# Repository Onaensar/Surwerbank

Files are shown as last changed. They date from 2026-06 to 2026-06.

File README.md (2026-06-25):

# Surwerbank
# Hybrid Powerbank: Solar + MagSafe + 18W Fast Charge 

Welcome to the **Hybrid Survivor Powerbank** repository! This project is a fully open-source, high-efficiency power management board designed for ultimate portability and outdoor resilience. 

Unlike standard powerbanks, this board integrates **18W Bidirectional Fast Charging**, **MPPT Solar Energy Harvesting**, and **MagSafe Compatible Wireless Charging** into a single, compact PCB.

**Designed by:** Abdullah Ensar 
**Institution:** İzmir Bakırçay University, Electrical and Electronics Engineering

---

## ✨ Key Features & Core ICs

### 1. ⚡ 18W Fast Charging & Power Management (IP5328P)
At the heart of the board is the **IP5328P** SoC, handling high-efficiency bi-directional charging. 
* Supports multiple fast-charge protocols (QC3.0, PD, AFC, FCP).
* Stable 5A output capability for demanding devices.
* Deeply filtered power delivery with strategic capacitor placement (low ripple).

### 2. ☀️ MPPT Solar Harvesting (CN3791)
Built for off-grid scenarios, the board includes a dedicated **CN3791** Maximum Power Point Tracking (MPPT) circuit.
* Connect a compatible solar panel to the terminal block.
* Extracts maximum available power from the sun to trickle-charge the lithium cells, significantly extending standby and active use time in outdoor environments.

### 3. 🧲 Wireless & MagSafe Charging (IP6808)
No cables? No problem. The **IP6808** wireless charging transmitter ensures your devices stay powered up seamlessly.
* Optimized resonance capacitor array for stable Tx transmission.
* Designed to be highly compatible with MagSafe form factors.

### 4. 🛡️ Rugged & Enclosure-Ready Mechanical Design
This PCB isn't just an electrical prototype; it is designed for real-world mechanical integration.
* **Mounting Holes:** M3 mounting holes placed at the corners for secure installation inside 3D printed or waterproof enclosures.
* **Optimized Clearances:** Type-C receptacle (J2) is perfectly aligned with the board edge (Edge.Cuts) to ensure flush mounting and cable compatibility.
* *Note: The mechanical STEP file is included for easy integration into Fusion 360 / SolidWorks to design custom rugged cases.*

---

## 🛠️ Fabrication & Assembly (Gerber Files)
The board has passed all DRC checks with 0 Errors and 0 Warnings in KiCad. 
* **Layer Count:** 2 Layers
* **Copper Weight:** 1 oz (recommended) or 2 oz for enhanced thermal dissipation under 5A loads.
* **Polygons:** Generous Top and Bottom GND pours with extensive via stitching for thermal relief and low impedance.

You can find the production-ready `.zip` file containing all Gerber and Drill files in the `Fabrication` folder.

## 📄 License
This project is released under the **Open Source Hardware (OSHW)** license. Feel free to use, modify, and build upon this design!

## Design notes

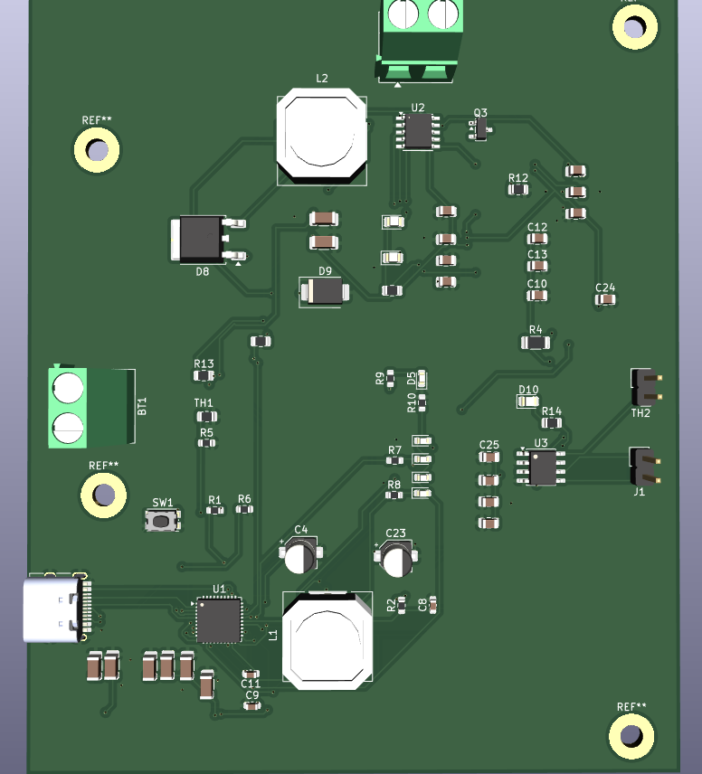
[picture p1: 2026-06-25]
Docs/3D_Render.png

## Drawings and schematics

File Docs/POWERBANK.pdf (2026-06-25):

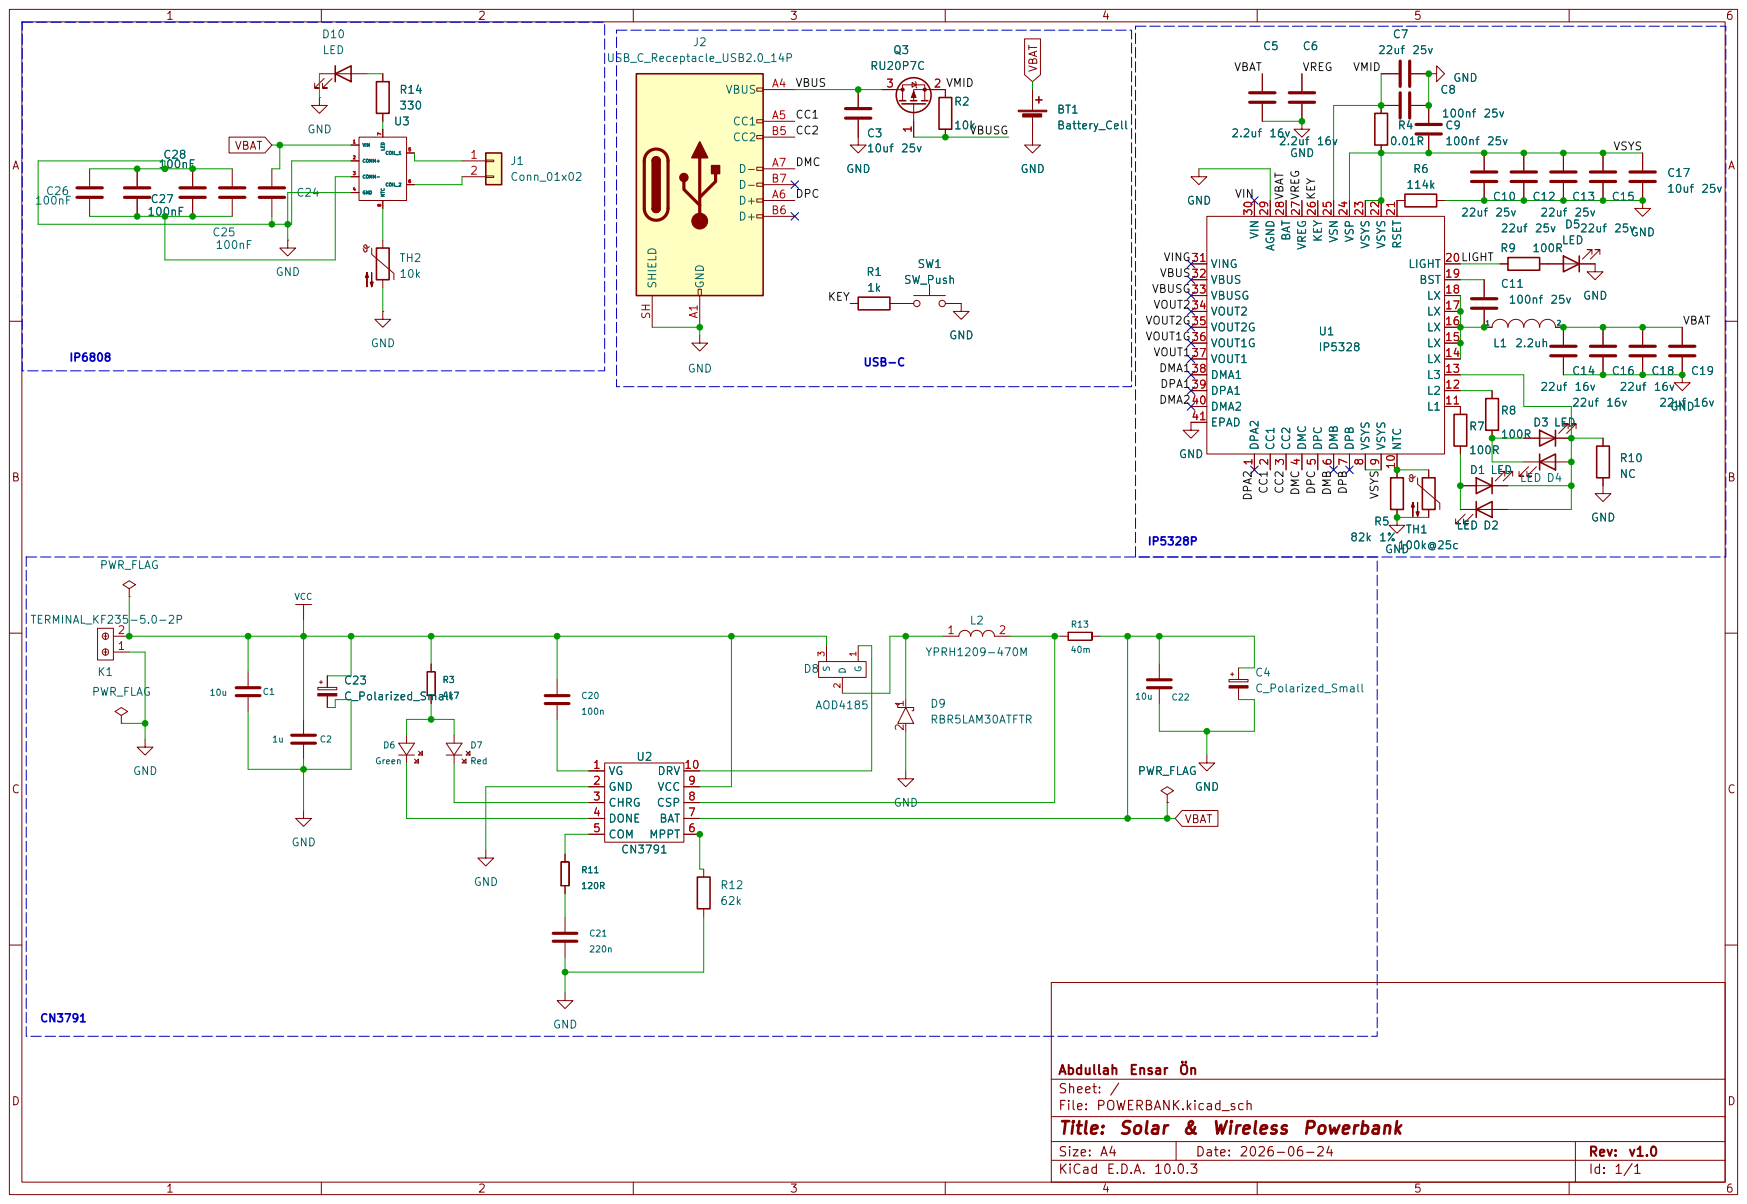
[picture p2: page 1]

VIN
L1 11 L2 12 L3 13 LX 14 LX 15 LX 16 LX 17 LX 18 BST 19 LIGHT 20 RSET 21 VSYS 22 VSYS 23 VSP 24 VSN 25 KEY 26 VREG 27 BAT 28 AGND 29 VIN 30

Abdullah Ensar Ön
Sheet: /
File: POWERBANK.kicad_sch
Title: Solar & Wireless Powerbank

Size: A4 | Rev: v1.0
KiCad E.D.A. 10.0.3 | Id: 1/1

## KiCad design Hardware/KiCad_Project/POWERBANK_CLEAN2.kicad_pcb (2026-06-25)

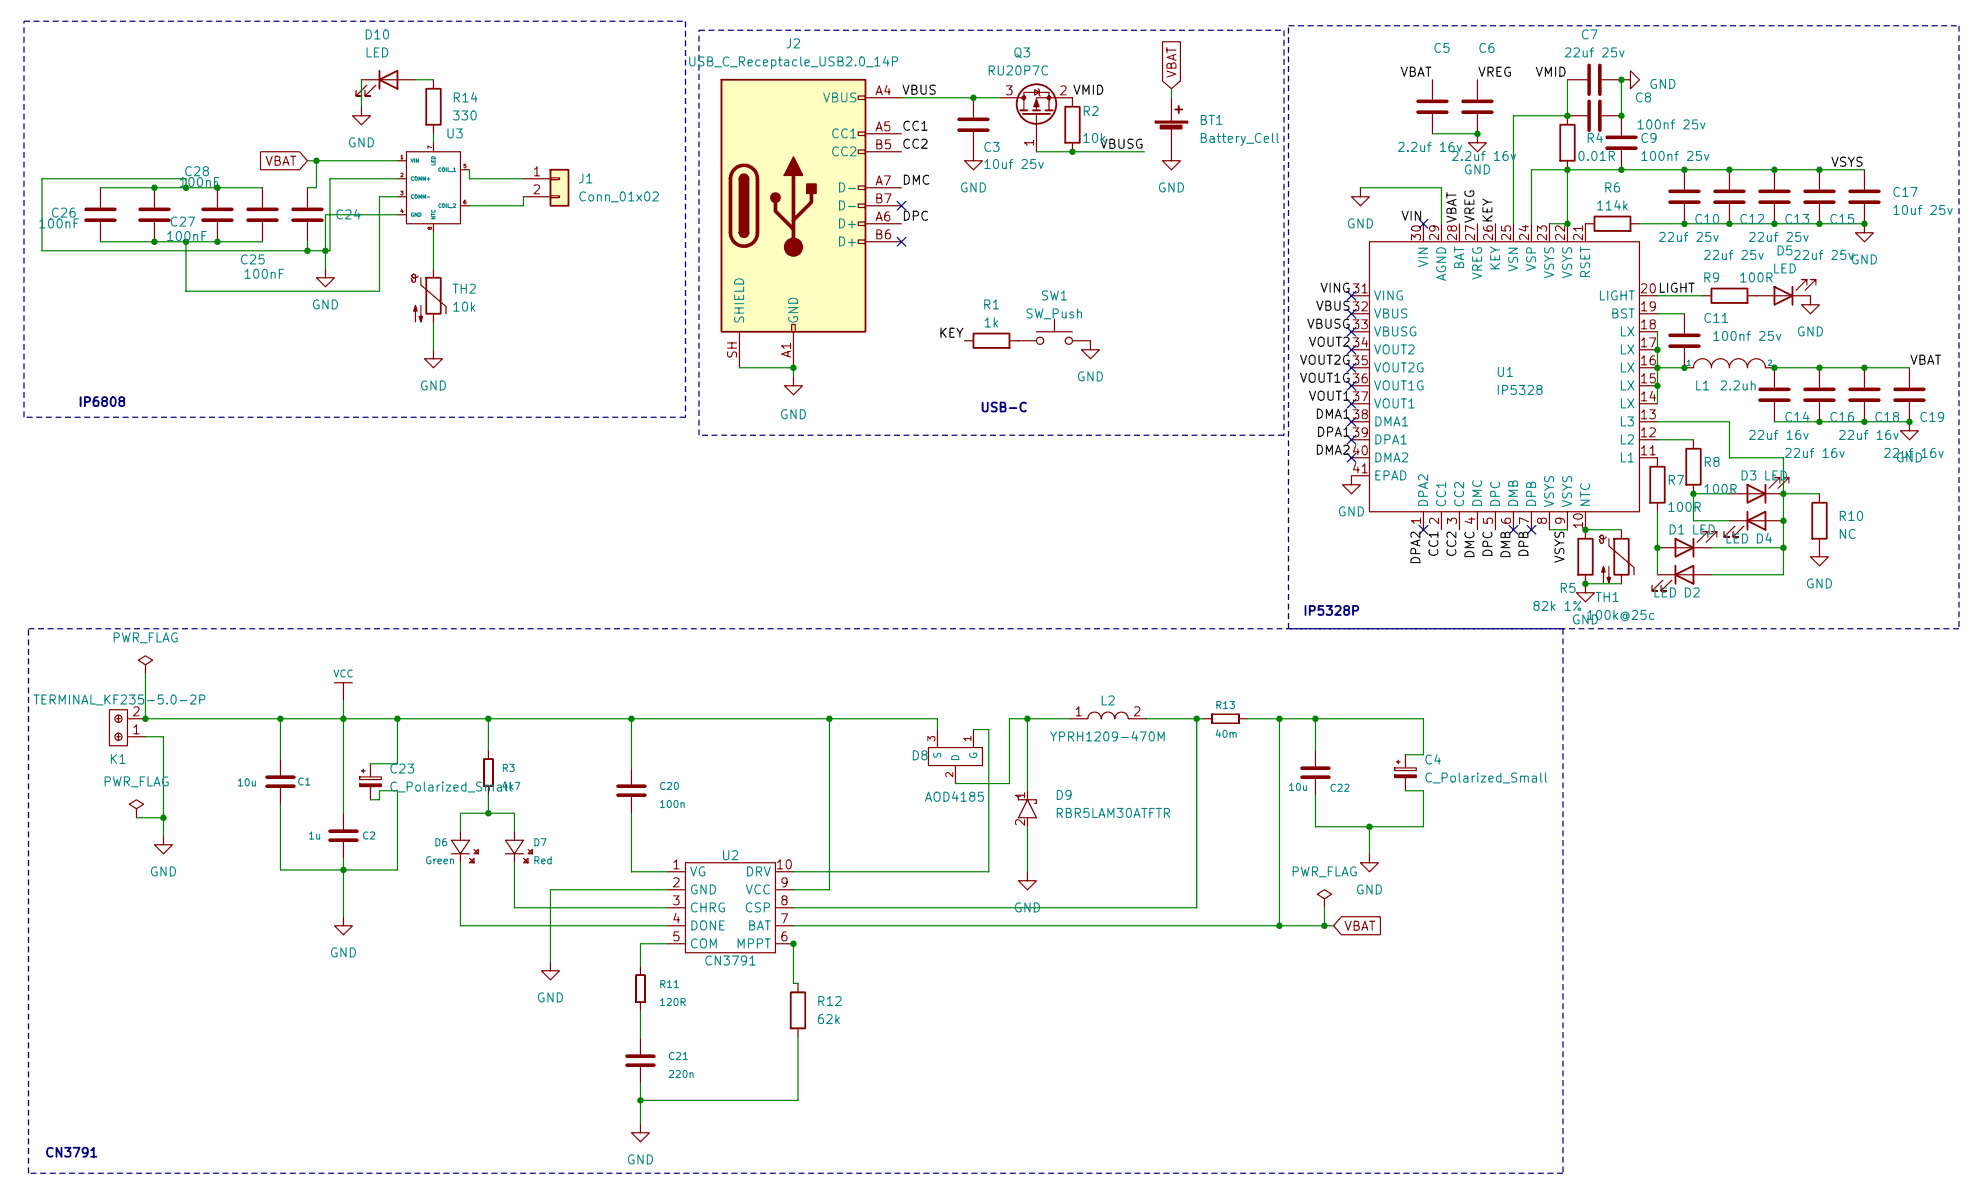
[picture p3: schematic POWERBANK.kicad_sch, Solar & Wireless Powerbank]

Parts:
BT1: Battery_Cell; TerminalBlock_Phoenix_MKDS-1,5-2-5.08_1x02_P5.08mm_Horizont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
C1, C22: 10u; C_0805_2012Metric
C2: 1u; C_0805_2012Metric
C3, C17: 10uf 25v; C_1206_3216Metric
C4, C23: C_Polarized_Small; CP_Elec_4x5.7
C5, C6: 2.2uf 16v; C_0805_2012Metric
C7, C15: 22uf 25v; C_1206_3216Metric
C8, C9, C11: 100nf 25v; C_0603_1608Metric
C10, C12, C13: 22uf 25v; C_0805_2012Metric
C14, C16, C18, C19: 22uf 16v; C_1206_3216Metric
C20: 100n; C_0805_2012Metric
C21: 220n; C_0805_2012Metric
C24: 10uF; C_0805_2012Metric
C25, C26, C27, C28: 100nF; C_0805_2012Metric
D1, D2, D3, D4, D5: LED; LED_0603_1608Metric
D6: Green; LED_0805_2012Metric
D7: Red; LED_0805_2012Metric
D8: AOD4185; TO-252-2
D9: RBR5LAM30ATFTR; D_SMB
D10: LED; LED_0805_2012Metric
J1: Conn_01x02; PinHeader_1x02_P2.54mm_Vertical
J2: USB_C_Receptacle_USB2.0_14P; USB_C_Receptacle_HRO_TYPE-C-31-M-12
K1: TERMINAL_KF235-5.0-2P; TerminalBlock_Phoenix_MKDS-1,5-2-5.08_1x02_P5.08mm_Horizont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
L1: 2.2uh; L_12x12mm_H4.5mm
L2: YPRH1209-470M; L_12x12mm_H4.5mm
Q3: RU20P7C; SOT-23
R1: 1k; R_0603_1608Metric
R2: 10k; R_0603_1608Metric
R3: 4k7; R_0805_2012Metric
R4: 0.01R; R_1206_3216Metric
R5: 82k 1%; R_0603_1608Metric
R6: 114k; R_0603_1608Metric
R7, R8, R9: 100R; R_0603_1608Metric
R10: NC; R_0603_1608Metric
R11: 120R; R_0805_2012Metric
R12: 62k; R_0805_2012Metric
R13: 40m; R_0805_2012Metric
R14: 330; R_0805_2012Metric
SW1: SW_Push; SW_Push_1P1T_NO_CK_KMR2
TH1: 100k@25c; R_0805_2012Metric
TH2: 10k; PinHeader_1x02_P2.54mm_Vertical
U1: IP5328; QFN-40-1EP_6x6mm_P0.5mm_EP4.6x4.6mm
U2: CN3791; SSOP-10_3.9x4.9mm_P1.00mm
U3: SOIC-8_3.9x4.9mm_P1.27mm

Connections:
/CC1: J2.A5 (CC1), U1.2 (CC1)
/CC2: J2.B5 (CC2), U1.3 (CC2)
/DMA1: U1.38 (DMA1)
/DMA2: U1.40 (DMA2)
/DMB: U1.6 (DMB)
/DMC: J2.A7 (D-), U1.4 (DMC)
/DPA1: U1.39 (DPA1)
/DPA2: U1.1 (DPA2)
/DPB: U1.7 (DPB)
/DPC: J2.A6 (D+), U1.5 (DPC)
/KEY: R1.1, U1.26 (KEY)
/LIGHT: R9.1, U1.20 (LIGHT)
/VBUS: C3.1, J2.A4 (VBUS), J2.A9 (VBUS), J2.B4 (VBUS), J2.B9 (VBUS), Q3.3 (D), U1.32 (VBUS)
/VBUSG: Q3.1 (G), R2.2, U1.33 (VBUSG)
/VIN: U1.30 (VIN)
/VING: U1.31 (VING)
/VMID: C7.1, C8.1, Q3.2 (S), R2.1, R4.1, U1.25 (VSN)
/VOUT1: U1.37 (VOUT1)
/VOUT1G: U1.36 (VOUT1G)
/VOUT2: U1.34 (VOUT2)
/VOUT2G: U1.35 (VOUT2G)
/VREG: C6.1, U1.27 (VREG)
/VSYS: C9.2, C10.1, C12.1, C13.1, C15.1, C17.1, R4.2, U1.8 (VSYS), U1.9 (VSYS), U1.22 (VSYS), U1.23 (VSYS), U1.24 (VSP)
GND: BT1.2 (-), C1.1, C2.1, C3.2, C4.2, C5.2, C6.2, C7.2, C8.2, C9.1, C10.2, C12.2, C13.2, C14.2, C15.2, C16.2, C17.2, C18.2, C19.2, C21.1, C22.1, C23.2, C24.2, C25.1, C26.1, C27.1, C28.1, D5.1 (K), D9.2 (A), D10.1 (K), J2.A1 (GND), J2.A12 (GND), J2.B1 (GND), J2.B12 (GND), J2.SH (SHIELD), K1.1, R5.2, R6.2, R10.2, R12.2, SW1.2, TH1.2, TH2.2, U1.29 (AGND), U1.41 (EPAD), U2.2 (GND), U3.2 (COMM+), U3.4 (GND)
unnamed: C11.2, L1.1, U1.14 (LX), U1.15 (LX), U1.16 (LX), U1.17 (LX), U1.18 (LX)
unnamed: C21.2, R11.1
unnamed: D1.2 (A), D2.1 (K), R7.2
unnamed: D1.1 (K), D2.2 (A), D3.1 (K), D4.2 (A), R10.1, U1.13 (L3)
unnamed: D3.2 (A), D4.1 (K), R8.2
unnamed: D5.2 (A), R9.2
unnamed: D6.1 (A), D7.1 (A), R3.1
unnamed: D6.2 (K), U2.4 (DONE)
unnamed: D7.2 (K), U2.3 (CHRG)
unnamed: D8.2 (D), D9.1 (C), L2.1
unnamed: D8.1 (G), U2.10 (DRV)
unnamed: D10.2 (A), R14.1
unnamed: J1.1, U3.5 (COIL_1)
unnamed: J1.2, U3.6 (COIL_2)
unnamed: R1.2, SW1.1
unnamed: C11.1, U1.19 (BST)
unnamed: R7.1, U1.11 (L1)
unnamed: R8.1, U1.12 (L2)
unnamed: R5.1, TH1.1, U1.10 (NTC)
unnamed: R6.1, U1.21 (RSET)
unnamed: R11.2, U2.5 (COM)
unnamed: L2.2, R13.1, U2.8 (CSP)
unnamed: R12.1, U2.6 (MPPT)
unnamed: C20.1, U2.1 (VG)
unnamed: C25.2, C26.2, C27.2, C28.2, U3.3 (COMM-)
unnamed: R14.2, U3.7 (LED)
unnamed: TH2.1, U3.8 (NTC)
VBAT: BT1.1 (+), C4.1, C5.1, C14.1, C16.1, C18.1, C19.1, C22.2, C24.1, L1.2, R13.2, U1.28 (BAT), U2.7 (BAT), U3.1 (VIN)
VCC: C1.2, C2.2, C20.2, C23.1, D8.3 (S), K1.2, R3.2, U2.9 (VCC)

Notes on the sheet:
IP5328P
CN3791
USB-C
IP6808

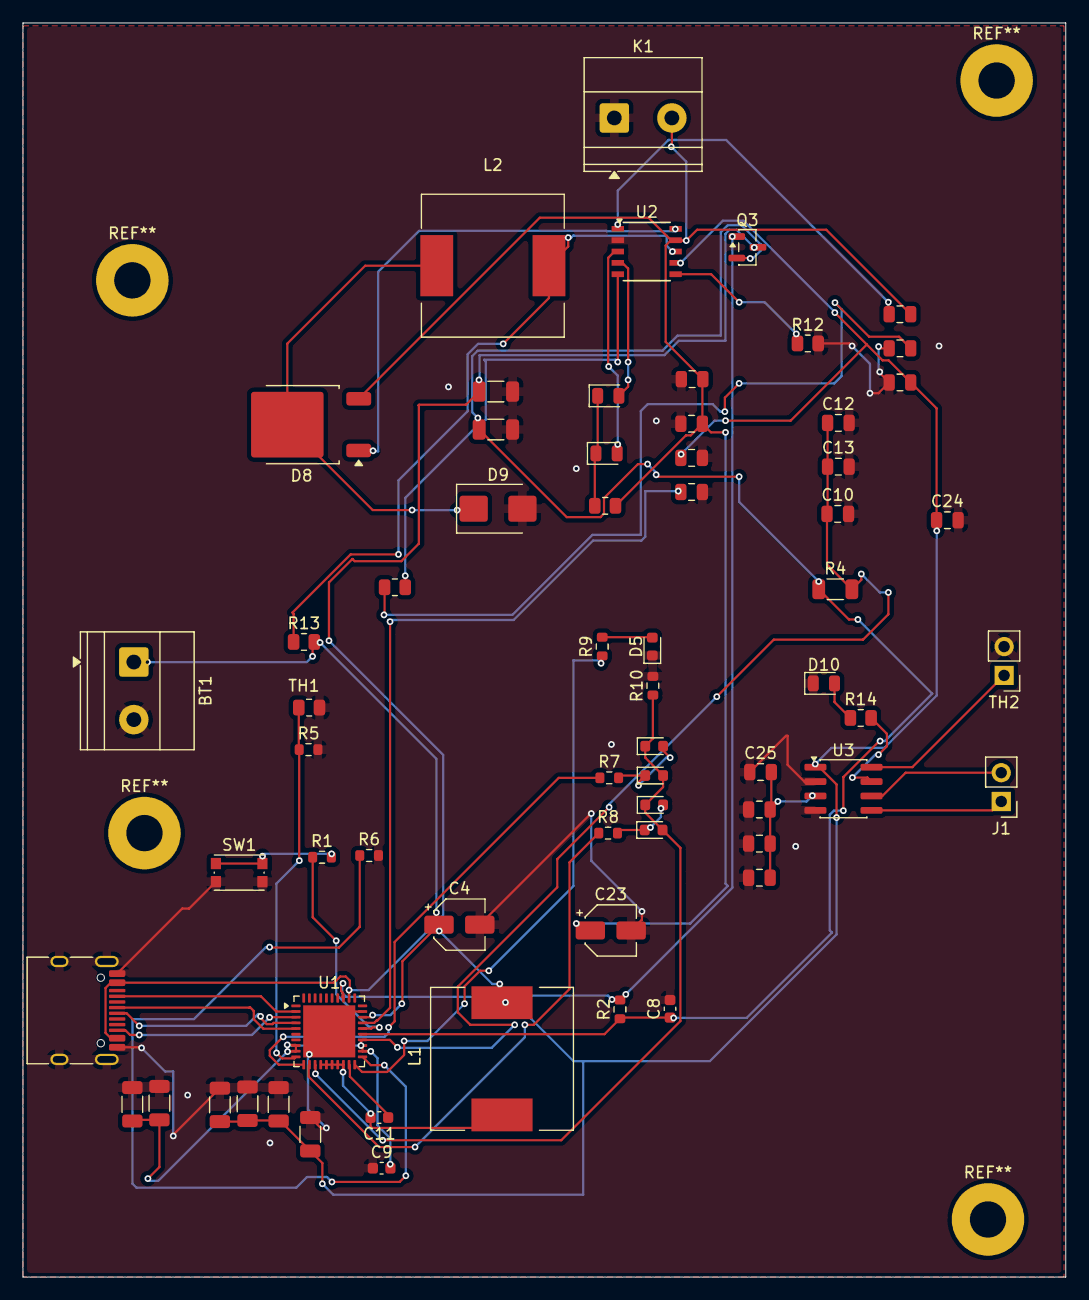
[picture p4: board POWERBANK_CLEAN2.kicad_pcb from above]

Board: 2 copper layers, 92.0 x 110.6 mm, 65 parts (0 on the bottom side), 41 nets.
